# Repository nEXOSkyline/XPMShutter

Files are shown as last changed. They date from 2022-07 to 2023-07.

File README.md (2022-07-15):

ABSTRACT
  
   In this project, we tested the efficacy of a new control box developed to override PC signal and increase functionality of the XPM. 
   Due to the high shutter reaction speed causing slight displacements in laser direction, the data recorded from the experiment was at 
   risk of being less accurate. To improve these measurements, we developed a new control system to decrease any directional variation and 
   increase the accuracy of the data. Along with this, being able to override the computer signal provides a manual alternative to keep the 
   shutter in a fixed state when necessary. (See Fig. 1)
       
INTRO

   nEXO (next-generation Enriched Xenon Observatory) is a proposed experiment in pursuit of a rare type of radioactive decay in 136Xe called
   neutrinoless double-beta decay. Xenon being the element of observation, it is necessary to measure the chemical purity of the liquid xenon
   (LXe) used in the experiment, since the presence of impurities can degrade the signal from the detector. To detect these impurities, a Xenon
   Purity Monitor (XPM) was developed and installed at SLAC National Accelerator Laboratory. This experiment is used as a method to determine
   which materials are suitable to be placed in direct contact with LXe in the detector.
   
METHODS AND MATERIALS

  For the experimental setup, we used the override control box to be tested, an Arduino Ethernet Shield 2, an external solenoid to simulate the 
  shutter, a spring, and a 300mH inductor. First, we tested the control box that was built with a single inductor to slow the shutter reaction 
  speed. While this slowed the initial pull of the solenoid, we found that the force exerted by the spring was too strong for the inductor to 
  affect its release speed. In an attempt to fix this, we added a second inductor, which still had negligible effect on the release speed. 
  (See Experimental Results) In addition to physical testing, we developed software to monitor the current measured across the “shutter” over
  time, as well as implement the theoretical idea of modifying the duty cycle of the PC signal and test the effect that this would have on our 
  setup.
  
EXPERIMENTAL RESULTS

  The results of this experiment showed that using a 300mH inductor improved the reaction of the laser shutter when closing, but not when 
  opening, and that the control box can successfully override the computer signal.

THEORETICAL RESULTS

  (Fig. 2) The simulated inductor current vs duty cycle data. In order to counteract the linear force of the spring, we will moderate the
  duty cycle from the PC, forcing the current change into a linear form.
  
CONCLUSION

  In conclusion, we found that we were able to electrically override the PC signal with the control box. Our next step toward improving the 
  efficacy of the override control system is to control the current using the Arduino, forcing a pulsing pattern instead of the constant 
  current previously tested. In theory, this would mean that we are able to gradually lower the current rather than stopping it completely.
  (See Fig. 2)

WORKS CITED

  Aspects of the R&D for the Enriched Xenon Observatory for double beta decay
  by Wamba, Kolo, PhD Thesis, Stanford University, 2007
  A Xenon Gas Purity Monitor for EXO
  by Dobi, A., SLAC National Accelerator Laboratory, 2011

This material is based upon work supported by the U.S. Department of Energy, Office of Science, Office of Nuclear Structure & Nuclear 
Astrophysics, Pathways to Improved Representation in Nuclear Science under Award Number DE-SC0021954.

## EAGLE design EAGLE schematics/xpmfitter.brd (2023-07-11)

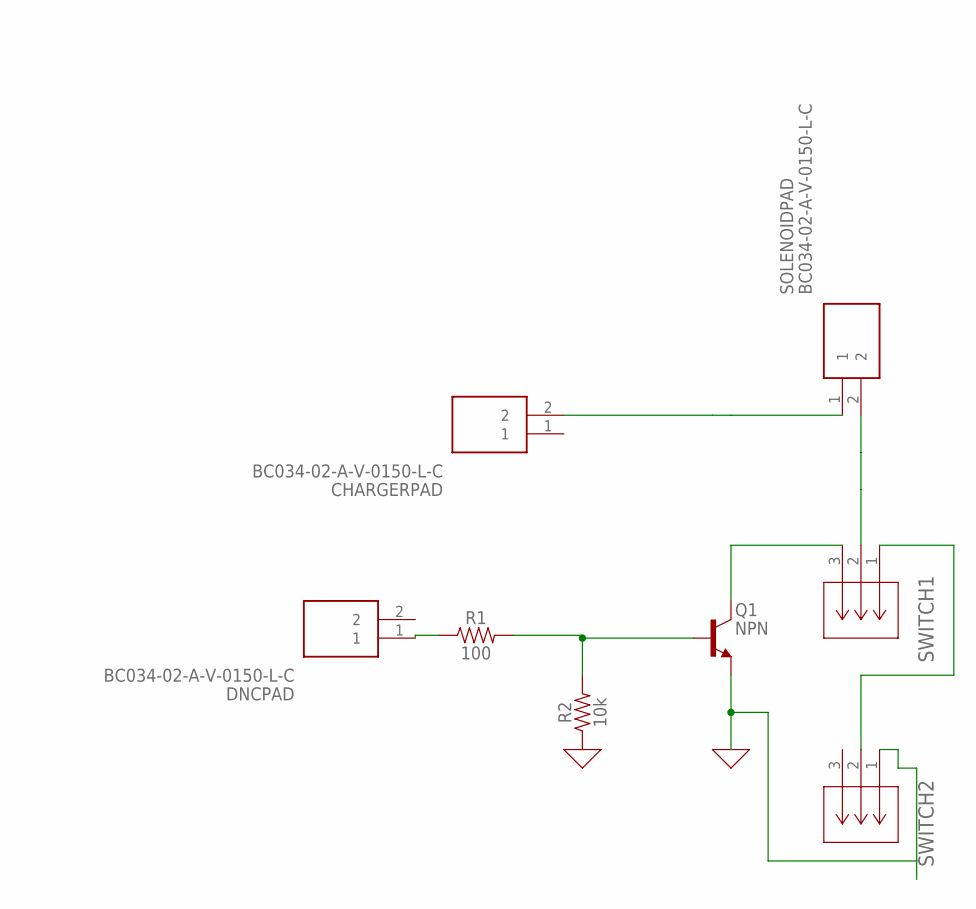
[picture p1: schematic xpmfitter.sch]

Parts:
CHARGERPAD: BC034-02-A-V-0150-L-C; BC03402AV0150LC
DNCPAD: BC034-02-A-V-0150-L-C; BC03402AV0150LC
Q1: NPN; SC59
R1: 100; 0603
R2: 10k; 0603
SOLENOIDPAD: BC034-02-A-V-0150-L-C; BC03402AV0150LC
SWITCH1, SWITCH2: GRPB031VWTC-RCCONN3_GRPB031_SUL; CONN3_GRPB031_SUL

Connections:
GND: Q1.E, R2.1, SWITCH2.1
unnamed: Q1.B, R1.2, R2.2
unnamed: Q1.C, SWITCH1.3
unnamed: CHARGERPAD.2, SOLENOIDPAD.1
unnamed: DNCPAD.1, R1.1
unnamed: SOLENOIDPAD.2, SWITCH1.2
unnamed: SWITCH1.1, SWITCH2.2

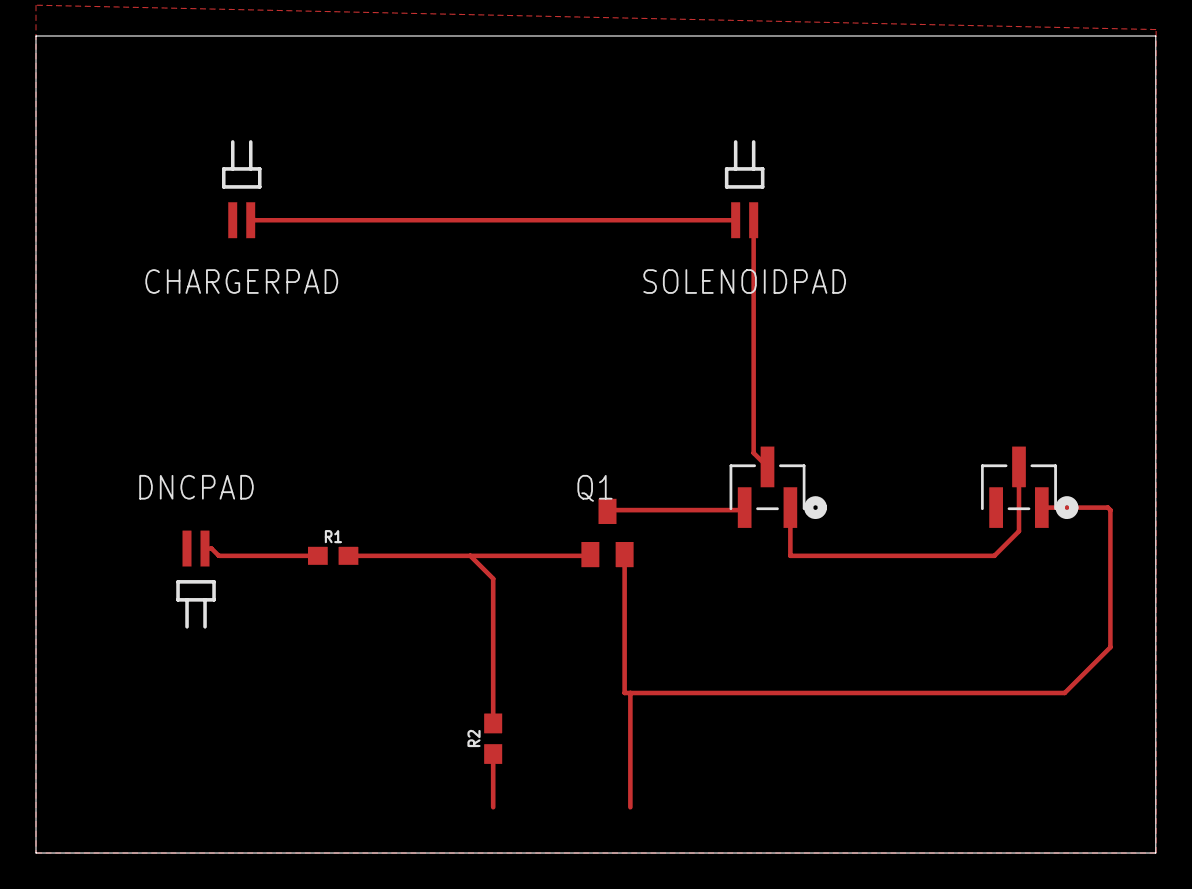
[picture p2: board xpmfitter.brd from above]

Board: 2 copper layers, 62.2 x 45.4 mm, 8 parts (0 on the bottom side), 7 nets.

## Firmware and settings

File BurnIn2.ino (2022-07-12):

/*
Program to simulate function generator for test XPM laser shutter control box
*/
#include <Ethernet.h>
//#include "HTTPSRedirect.h"


byte mac[] = { 0xA8, 0x61, 0x0A, 0xAE, 0x71, 0x1F };
IPAddress ip(10, 0, 0, 4); // example IPAddress ip(192, 168, 1, 100);
IPAddress gateway(10, 0, 0, 1);
IPAddress dns(10, 0, 0, 1);
IPAddress subnet(255, 255, 255, 0);
EthernetClient client;
EthernetServer ser = EthernetServer(5047);
String msg;

void setup() {
  Serial.begin(9600);
  while (!Serial) {
    ; // wait for serial port to connect. Needed for native USB port only
  }
  Serial.print("Hello\n");
  // start the Ethernet connection:
  Ethernet.begin(mac, ip);
    //Serial.println("Failed to configure Ethernet using DHCP");
    // try to congifure using IP address instead of DHCP:
    //Ethernet.begin(mac, ip);

  // give the Ethernet shield a second to initialize:
  delay(1000);
}

void receive()
{
    msg = String(""); 
    char c = '$';
    while( c != '\n' )
    {
      c = client.read();
      if( c<0 ) break;
      if( c>=0 ) msg = msg + String(c);
    }
    Serial.println(msg);
}


void wait_and_update(int sec) {
    for(int i = 0; i < sec; i++) {
      delay(1000);  // wait for 1 s
      float val = analogRead(A4); // read data
      String string_volt = String(val, DEC);
      receive();
      //Serial.println(msg.c_str());
      if( msg.startsWith( String("CWON") ) ) digitalWrite(13, HIGH);
      else if( msg.startsWith( String("CWOFF") ) ) digitalWrite(13, LOW);
      else
      {
        client.print(string_volt+String("\n")); // print data
        Serial.println (String("Sent ") + string_volt+String("\n"));
      }
   }
}

void pulse_it(int duration, float DC) {  //duration value in ms, DC percentage

  int cycles = duration;
  float t_on = 10*DC/100; //delay time when energized
  float t_off = 10 - t_on;  //delay time when de-energized

  for(int i = 0; i < cycles || cycles < 0; i++) {
    digitalWrite(13, LOW);  //de-energize solenoid
    delay(t_off); // wait for t_off ms
    digitalWrite(13, HIGH); //energize solenoid
    delay(t_on);  // wait for t_on ms
    if(i % 100 == 0) {
      float val = analogRead(A4); // read data
      String string_volt = String(val, DEC);
      receive();
      client.print(string_volt+String("\n")); // print data
      if( msg.startsWith( String("OFF") ) )
      {
        digitalWrite(13, LOW);  //de-energize solenoid
        break;
      }
    }
  }
}

void loop() {
  Serial.println("connecting");

  client = ser.available();
  while(!client) client = ser.available();
  Serial.println("connected!");
  if(client) 
  {
    // read bytes from the incoming client and write them back
    // to any clients connected to the server:
    float duty;
    /*
    receive();
    if( !msg.startsWith(String("CW")) && !msg.startsWith(String("OFF")) && !msg.startsWith(String("???")) )
    {
       duty = msg.toFloat();
       pulse_it( -1 , duty );
    }
    Serial.println(msg);
    */
    digitalWrite(13, LOW);  // de-energize solenoid
    wait_and_update(300);  // wait for 300 s
    digitalWrite(13, HIGH); // energize solenoid
    wait_and_update(32); // wait for 32 s
    digitalWrite(13, LOW);  // de-energize solenoid
    wait_and_update(14400);  // wait 4 hours (4*60*60) s
    digitalWrite(13, HIGH); // energize solenoid
    wait_and_update(258);  // wait for 258 s
  }
}

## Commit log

2023-05-17 Add files via upload
    A GUI which allows the user to commit two values each for current pulses and pauses used to control the motion of a solenoid.
2023-07-11 Add files via upload
    files for printed board
    [xpmfitter.brd, xpmfitter.sch]

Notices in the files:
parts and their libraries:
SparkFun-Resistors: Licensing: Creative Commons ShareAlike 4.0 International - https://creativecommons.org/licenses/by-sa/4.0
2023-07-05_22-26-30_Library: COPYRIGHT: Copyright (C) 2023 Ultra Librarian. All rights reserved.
